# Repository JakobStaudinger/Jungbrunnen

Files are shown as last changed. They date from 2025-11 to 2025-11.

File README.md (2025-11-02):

# Jungbrunnen
An embedded project using a Raspberry Pi Pico to strobe LEDs to make it look like water droplets are floating in mid-air.
Heavily inspired by [isaac879's RGB Time Fountain](https://github.com/isaac879/RGB-Time-Fountain)

> [!WARNING]
> 🚧 Under development 🚧

## Firmware
Firmware for the cyw43 chip can be found [here](https://github.com/embassy-rs/embassy/tree/main/cyw43-firmware). It should be placed in the `cyw43-firmware` folder to make the program compile.

### Dev Firmware
To reduce the time it takes to flash the program to the Pico, you can enable the `dev_firmware` feature. This makes it so the firmware doesn't get embedded into the binary, and instead the program assumes it is already located at a fixed memory address.

You need to ensure the firmware is actually pre-baked into the flash memory. To do this, use the `probe-rs download` command, like so:
```console
$ probe-rs download cyw43-firmware/43439A0.bin --binary-format bin --chip RP2040 --base-address 0x10100000
$ probe-rs download cyw43-firmware/43439A0_clm.bin --binary-format bin --chip RP2040 --base-address 0x10140000
```

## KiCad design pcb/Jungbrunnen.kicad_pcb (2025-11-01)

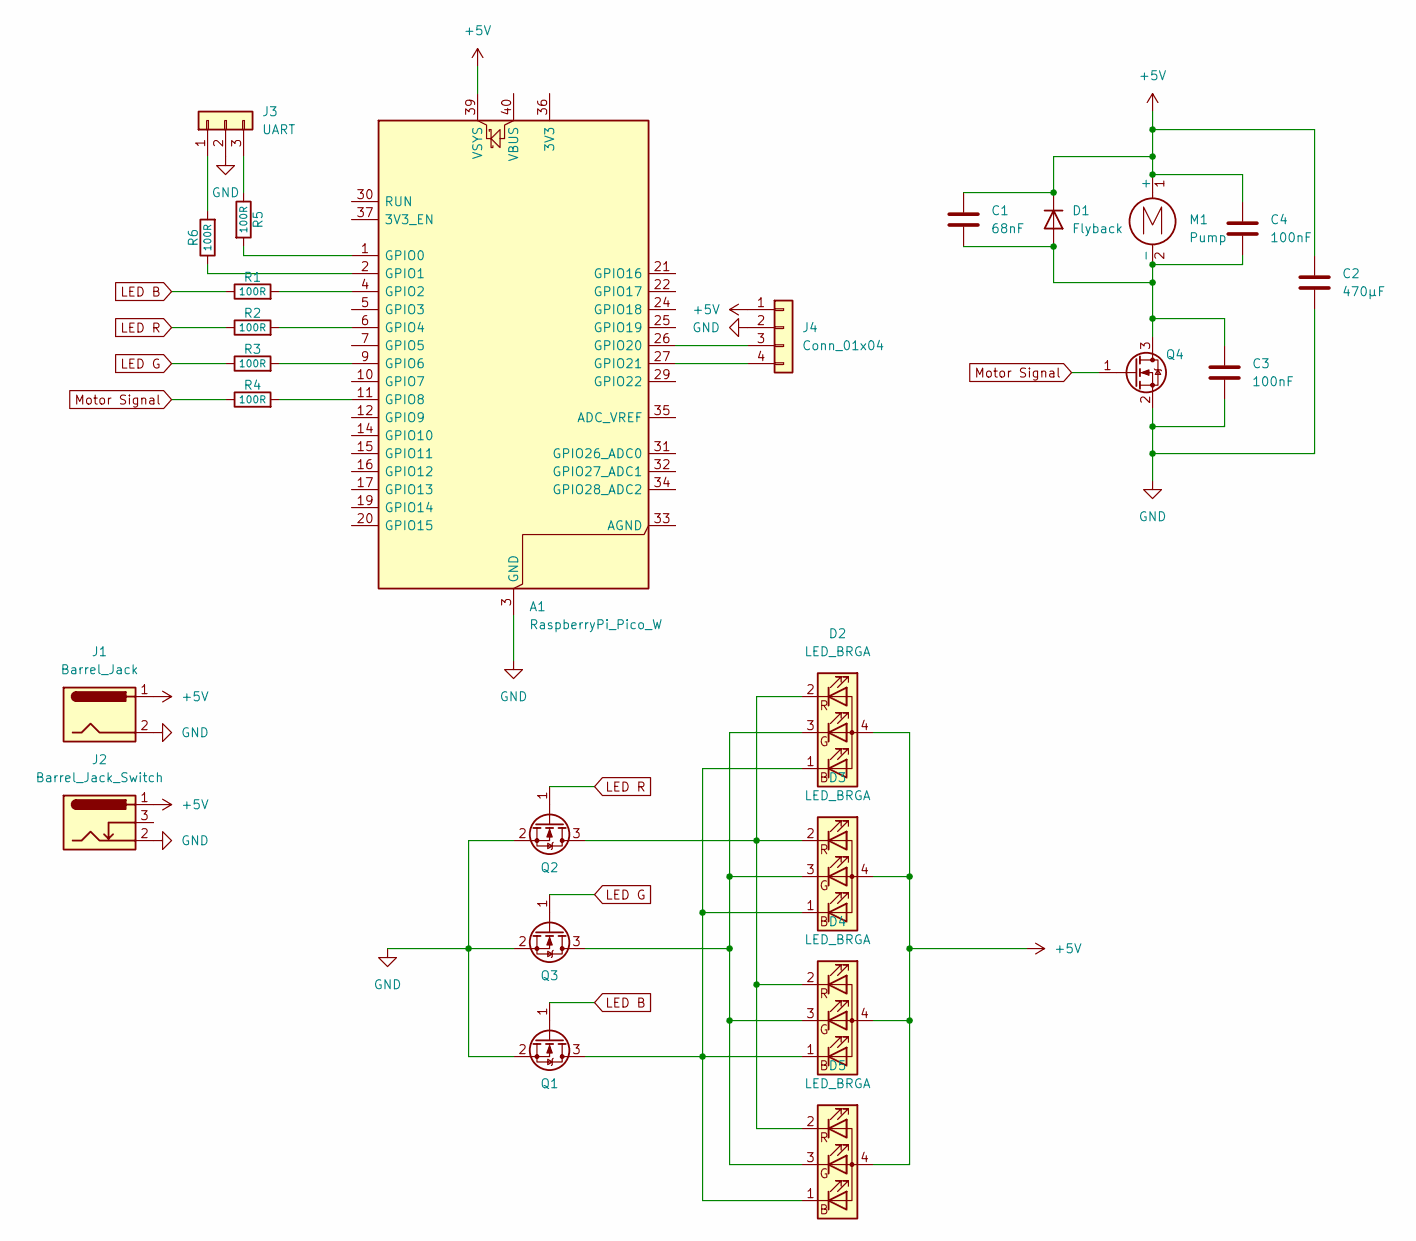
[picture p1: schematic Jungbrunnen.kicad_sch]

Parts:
A1: RaspberryPi_Pico_W; RaspberryPi_Pico_Common_THT
C1: 68nF; C_0805_2012Metric
C2: 470µF; C_Elec_8x10.2
C3, C4: 100nF; C_0805_2012Metric
D1: Flyback; D_SMA
D2, D3, D4, D5: LED_BRGA; JST_XH_B4B-XH-A_1x04_P2.50mm_Vertical
J1: Barrel_Jack; JST_XH_B2B-XH-A_1x02_P2.50mm_Vertical_Alternate
J2: Barrel_Jack_Switch; BarrelJack_Horizontal
J3: UART; JST_SH_SM03B-SRSS-TB_1x03-1MP_P1.00mm_Horizontal
J4: Conn_01x04; PinHeader_1x04_P2.54mm_Vertical
M1: Pump; JST_XH_B2B-XH-A_1x02_P2.50mm_Vertical_Alternate
Q1, Q2, Q3, Q4: AO3400A; SOT-23
R1, R2, R3, R4, R5, R6: 100R; R_0603_1608Metric

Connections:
+5V: A1.39 (VSYS), C1.1, C2.1, C4.1, D1.1 (K), D2.4 (A), D3.4 (A), D4.4 (A), D5.4 (A), J1.1, J2.1, J4.1, M1.1 (+)
GND: A1.3 (GND), A1.8 (GND), A1.13 (GND), A1.18 (GND), A1.23 (GND), A1.28 (GND), A1.38 (GND), C2.2, C3.2, J1.2, J2.2, J3.2, J4.2, Q1.2 (S), Q2.2 (S), Q3.2 (S), Q4.2 (S)
LED B: Q1.1 (G), R1.1
LED G: Q3.1 (G), R3.1
LED R: Q2.1 (G), R2.1
Motor Signal: Q4.1 (G), R4.1
unnamed: A1.1 (GPIO0), R5.2
unnamed: A1.2 (GPIO1), R6.1
unnamed: A1.4 (GPIO2), R1.2
unnamed: A1.6 (GPIO4), R2.2
unnamed: A1.9 (GPIO6), R3.2
unnamed: A1.11 (GPIO8), R4.2
unnamed: A1.26 (GPIO20), J4.3
unnamed: A1.27 (GPIO21), J4.4
unnamed: C1.2, C3.1, C4.2, D1.2 (A), M1.2 (-), Q4.3 (D)
unnamed: D2.1 (BK), D3.1 (BK), D4.1 (BK), D5.1 (BK), Q1.3 (D)
unnamed: D2.3 (GK), D3.3 (GK), D4.3 (GK), D5.3 (GK), Q3.3 (D)
unnamed: D2.2 (RK), D3.2 (RK), D4.2 (RK), D5.2 (RK), Q2.3 (D)
unnamed: J3.1, R6.2
unnamed: J3.3, R5.1

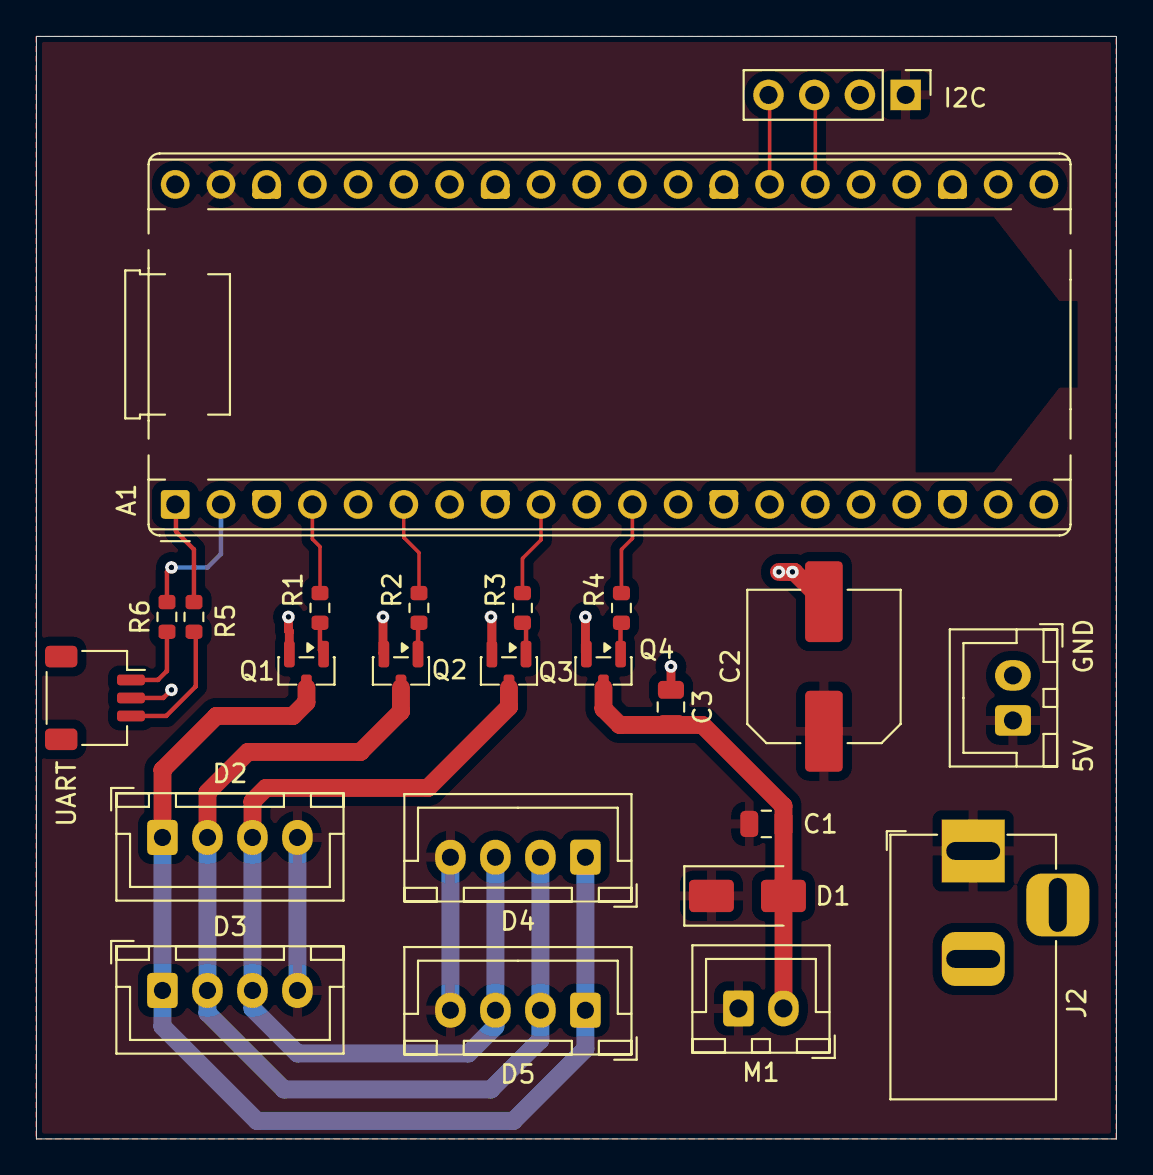
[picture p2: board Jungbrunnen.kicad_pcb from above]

Board: 2 copper layers, 60.0 x 61.2 mm, 24 parts (0 on the bottom side), 20 nets.

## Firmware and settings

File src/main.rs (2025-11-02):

#![no_std]
#![no_main]

mod led_orchestrator;
mod mqtt;
mod network;
mod peripherals;
mod stream;

use defmt::*;
use embassy_executor::Spawner;
use embassy_rp::{self, pac::SIO};
use embassy_sync::blocking_mutex::raw::CriticalSectionRawMutex;
use embassy_sync::channel::Channel;
use embassy_sync::pubsub::{PubSubChannel, WaitResult};
use embassy_time::{Instant, Timer};
use indoc::indoc;
use static_cell::StaticCell;

use crate::led_orchestrator::orchestrate_leds;
use crate::mqtt::{
    ConnectionOptions, Credentials, MqttRunner, MqttRxSubscriber, MqttTxSender, RxPacket,
    SubscribeTopic, TxPacket, mqtt_heartbeat, mqtt_task,
};
use crate::network::{Cyw43, network_task, wifi_task};
use crate::peripherals::{AssignedResources, LedPeripherals, WifiPeripherals};

use {defmt_rtt as _, panic_probe as _};

#[embassy_executor::task]
async fn mqtt_autodiscovery_task(
    mut subscriber: MqttRxSubscriber<'static>,
    sender: MqttTxSender<'static>,
) {
    loop {
        let command = subscriber.next_message().await;
        let command = match command {
            WaitResult::Lagged(num) => {
                warn!("Lagged {} messages behind!", num);
                continue;
            }
            WaitResult::Message(command) => command,
        };

        if let RxPacket::Connected = command {
            sender
                .send(TxPacket::Subscribe(&[
                    SubscribeTopic {
                        qos: mqttrs::QoS::AtMostOnce,
                        topic_path: "picow/light/set",
                    },
                    SubscribeTopic {
                        qos: mqttrs::QoS::AtMostOnce,
                        topic_path: "picow/light/brightness/set",
                    },
                ]))
                .await;

            let autodiscovery = TxPacket::Publish {
                qospid: mqttrs::QosPid::AtMostOnce,
                topic_name: "homeassistant/device/picow/config",
                payload: indoc! {
                r#"{
                        "device": {
                            "identifiers": ["picow"],
                            "name": "PicoW",
                            "model": "Rasperry Pi Pico W",
                            "manufacturer": "Raspberry Pi"
                        },
                        "origin": {
                            "name": "Test"
                        },
                        "components": {
                        }
                    }"#
                }
                .as_bytes(),
            };

            sender.send(autodiscovery).await;
        }
    }
}

#[embassy_executor::main]
async fn main(spawner: Spawner) {
    let locked_state = SIO.spinlock_st();
    info!("Spinlock state {:b}", locked_state.read());

    SIO.spinlock(31).write_value(1);

    let p = embassy_rp::init(Default::default());
    let p = split_resources!(p);

    let (cyw43, runner) = Cyw43::new(p.wifi).await;

    spawner.must_spawn(wifi_task(runner));

    let cyw43 = cyw43.init().await;

    const CLIENT_NAME: &str = "picow";

    let (cyw43, runner) = cyw43.init_stack(CLIENT_NAME).await;

    spawner.must_spawn(network_task(runner));

    let ssid = env!("WIFI_SSID");
    let password = env!("WIFI_PASSWORD");
    let cyw43 = cyw43.join(ssid, password).await;

    let mqtt_runner = MqttRunner::new(
        cyw43.stack(),
        ConnectionOptions {
            address: mqtt::ServerAddress::HostName("homeassistant"),
            client_id: "picow",
            credentials: Credentials {
                username: "picow",
                password: "picow".as_bytes(),
            }
            .into(),
        },
    );

    static MQTT_TX_CHANNEL: StaticCell<Channel<CriticalSectionRawMutex, TxPacket, 10>> =
        StaticCell::new();

    let tx_channel = MQTT_TX_CHANNEL.init(Channel::new());

    static MQTT_RX_CHANNEL: StaticCell<
        PubSubChannel<CriticalSectionRawMutex, RxPacket, 10, 10, 1>,
    > = StaticCell::new();
    let rx_channel = MQTT_RX_CHANNEL.init(PubSubChannel::new());

    let autodiscovery_subscriber = rx_channel.subscriber().unwrap();

    spawner.must_spawn(mqtt_task(
        mqtt_runner,
        tx_channel.receiver(),
        rx_channel.publisher().unwrap(),
    ));
    spawner.must_spawn(mqtt_heartbeat(tx_channel.sender()));
    spawner.must_spawn(mqtt_autodiscovery_task(
        autodiscovery_subscriber,
        tx_channel.sender(),
    ));

    spawner.must_spawn(orchestrate_leds(p.led));

    loop {
        Timer::at(Instant::MAX).await
    }
}

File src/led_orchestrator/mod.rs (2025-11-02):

use defmt::*;
use embassy_futures::{join::join4, yield_now};
use embassy_rp::{
    bind_interrupts,
    clocks::clk_sys_freq,
    dma::{AnyChannel, Channel, Word},
    pac::{self, dma::regs::CtrlTrig},
    peripherals::PIO1,
    pio::{InterruptHandler, Pio, ShiftConfig},
    pwm::{self, Pwm, Slice},
};
use embassy_time::Duration;
use fixed::{FixedU32, types::extra::U8};
use heapless::Vec;
use pio::pio_asm;

use crate::{
    peripherals::LedPeripherals,
    stream::{self, Color, ColorStepIterator, Hz, StreamConfig},
};

bind_interrupts!(struct Irqs {
    PIO1_IRQ_0 => InterruptHandler<PIO1>;
});

#[embassy_executor::task]
pub async fn orchestrate_leds(mut p: LedPeripherals) {
    let mut pio = Pio::new(p.pio, Irqs);

    let timing_program = pio_asm! {
        r#"
            .define public MICROS_PER_TICK 64
            .define public TICK_OVERHEAD 5
            wait 0 irq 0

        .wrap_target
            out y 8
            in null 8
            in y 8
            out x 24
        delay:
            jmp x-- delay
        .wrap
        "#
    };

    let mut timing_config = embassy_rp::pio::Config::default();
    timing_config.use_program(&pio.common.load_program(&timing_program.program), &[]);
    let target_frequency = 1_000_000 / timing_program.public_defines.MICROS_PER_TICK;
    let clock_divider = (clk_sys_freq() as f64) / (target_frequency as f64);
    timing_config.clock_divider = FixedU32::<U8>::checked_from_num(clock_divider).unwrap();
    timing_config.shift_out = ShiftConfig {
        direction: embassy_rp::pio::ShiftDirection::Left,
        auto_fill: true,
        threshold: 32,
    };
    timing_config.shift_in = ShiftConfig {
        direction: embassy_rp::pio::ShiftDirection::Left,
        auto_fill: true,
        threshold: 16,
    };

    let mut pwm_config = pwm::Config::default();
    pwm_config.enable = true;
    pwm_config.top = 254;

    let pwm_slice_red = p.red_slice.number();
    let pwm = Pwm::new_output_a(p.red_slice, p.red_pin, pwm_config.clone());
    core::mem::forget(pwm);

    sync_pio_to_pwm(
        [*p.dma_pwm_red_a.into(), *p.dma_pwm_red_b.into()],
        pwm_slice_red,
        1,
        0,
    );

    let pwm_slice_green = p.green_slice.number();
    let pwm = Pwm::new_output_a(p.green_slice, p.green_pin, pwm_config.clone());
    core::mem::forget(pwm);

    sync_pio_to_pwm(
        [*p.dma_pwm_green_a.into(), *p.dma_pwm_green_b.into()],
        pwm_slice_green,
        1,
        1,
    );

    let pwm_slice_blue = p.blue_slice.number();
    let pwm = Pwm::new_output_a(p.blue_slice, p.blue_pin, pwm_config.clone());
    core::mem::forget(pwm);

    sync_pio_to_pwm(
        [*p.dma_pwm_blue_a.into(), *p.dma_pwm_blue_b.into()],
        pwm_slice_blue,
        1,
        2,
    );

    pio.sm0.set_config(&timing_config);
    pio.sm0.set_enable(true);

    pio.sm1.set_config(&timing_config);
    pio.sm1.set_enable(true);

    pio.sm2.set_config(&timing_config);
    pio.sm2.set_enable(true);

    pio.irq_flags.set_all(0);

    let mut config = stream::Config::new(
        &[
            StreamConfig::new(Color(255, 0, 0), Hz(60.), Duration::from_millis(3), None),
            StreamConfig::new(
                Color(0, 255, 255),
                Hz(60.5),
                Duration::from_millis(3),
                Some(Duration::from_millis(500)),
            ),
            StreamConfig::new(
                Color(0, 255, 00),
                Hz(59.5),
                Duration::from_millis(3),
                Some(Duration::from_millis(2500)),
            ),
        ],
        timing_program.public_defines.MICROS_PER_TICK,
        timing_program.public_defines.TICK_OVERHEAD,
    )
    .into_iter();

    let (mut red, mut green, mut blue) = calculate_next_buffer::<_, 2048>(&mut config).await;

    loop {
        info!("Loop");

        let ((r, g, b), _, _, _) = join4(
            calculate_next_buffer(&mut config),
            pio.sm0.tx().dma_push(p.dma_pio_red.reborrow(), &red, false),
            pio.sm1
                .tx()
                .dma_push(p.dma_pio_green.reborrow(), &green, false),
            pio.sm2
                .tx()
                .dma_push(p.dma_pio_blue.reborrow(), &blue, false),
        )
        .await;

        red = r;
        green = g;
        blue = b;
    }
}

async fn calculate_next_buffer<const NUM_STREAMS: usize, const BUFFER_SIZE: usize>(
    config: &mut ColorStepIterator<NUM_STREAMS>,
) -> (
    Vec<u32, BUFFER_SIZE>,
    Vec<u32, BUFFER_SIZE>,
    Vec<u32, BUFFER_SIZE>,
) {
    let mut red = Vec::new();
    let mut green = Vec::new();
    let mut blue = Vec::new();

    while !red.is_full() {
        let next = config.next().unwrap();

        red.push(next.encode_red()).unwrap();
        green.push(next.encode_green()).unwrap();
        blue.push(next.encode_blue()).unwrap();

        yield_now().await;
    }

    return (red, green, blue);
}

fn sync_pio_to_pwm(dmas: [AnyChannel; 2], pwm_slice: usize, pio_number: u8, sm: u8) {
    let raw_pwm = pac::PWM.ch(pwm_slice);

    let treq_sel = pac::dma::vals::TreqSel::from(pio_number * 8 + sm + 4);

    let [first_dma, second_dma] = dmas;
    let r = first_dma.regs();

    r.write_addr().write_value(raw_pwm.cc().as_ptr() as u32);
    r.read_addr()
        .write_value(pac::PIO1.rxf(sm as usize).as_ptr() as u32);
    r.trans_count().write_value(u32::MAX);
    r.al1_ctrl().write(|val| {
        let mut w = CtrlTrig(0);
        w.set_treq_sel(treq_sel);
        w.set_data_size(u16::size());
        w.set_chain_to(second_dma.number());
        w.set_incr_read(false);
        w.set_incr_write(false);
        w.set_en(true);

        *val = w.0;
    });

    let r = second_dma.regs();

    r.write_addr().write_value(raw_pwm.cc().as_ptr() as u32);
    r.read_addr()
        .write_value(pac::PIO1.rxf(sm as usize).as_ptr() as u32);
    r.trans_count().write_value(u32::MAX);
    r.ctrl_trig().write(|w| {
        w.set_treq_sel(treq_sel);
        w.set_data_size(u16::size());
        w.set_chain_to(first_dma.number());
        w.set_incr_read(false);
        w.set_incr_write(false);
        w.set_en(true);
    });
}

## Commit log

2025-09-04 WIP: Implement strobing of LEDs
2025-09-05 control LEDs with PIO
2025-10-12 refactor: move LED orchestration into separate task
2025-11-01 feat: add PCB designs
    [Jungbrunnen.kicad_pcb, Jungbrunnen.kicad_sch]
2025-11-02 fix: stop stuttering when calculating next batch of color values
    [main.rs, mod.rs]
